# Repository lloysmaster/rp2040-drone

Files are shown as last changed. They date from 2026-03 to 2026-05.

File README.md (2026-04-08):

# 🛸 RP2040 Custom Flight Controller (PicoDrone)





Proyecto de **Controladora de Vuelo (FC)** desarrollada desde cero para el microcontrolador **RP2040**. Este firmware aprovecha las capacidades de hardware de la Raspberry Pi Pico (específicamente los bloques PIO) para gestionar protocolos de baja latencia.
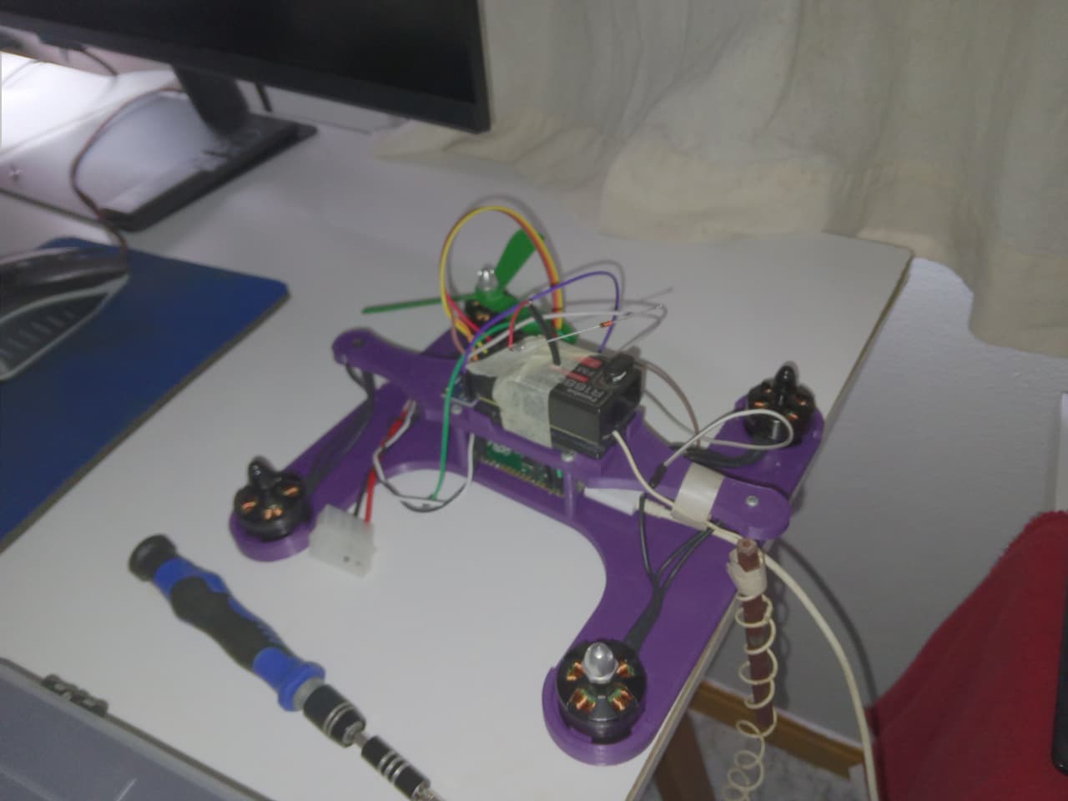
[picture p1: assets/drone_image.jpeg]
drone_image


[configurador personalizado](https://lloysmaster.github.io/)
/
 [repositorio](https://github.com/lloysmaster/lloysmaster.github.io)
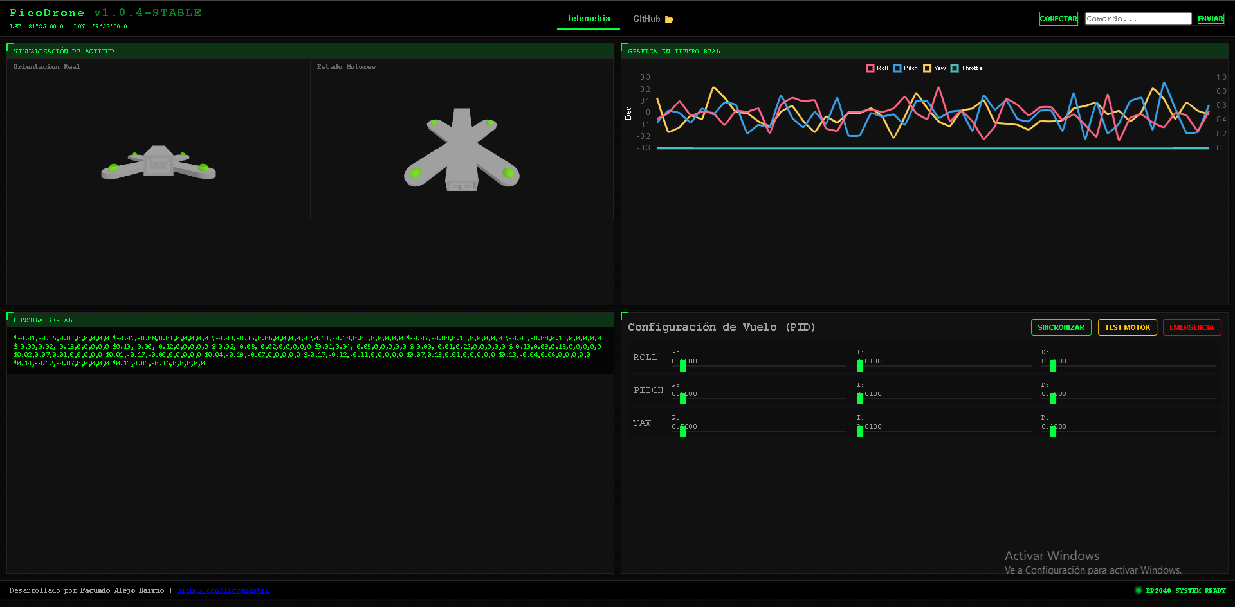
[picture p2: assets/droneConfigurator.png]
drone_image


---

## 🛠️ Especificaciones Técnicas

| Componente | Detalle | Protocolo/Conexión |
| :--- | :--- | :--- |
| **MCU** | Raspberry Pi Pico (RP2040) | Dual Core @ 125MHz |
| **IMU** | MPU6500 | **SPI** (Alta Velocidad) |
| **ESC** | BLHeli_S 20A | **DShot300** via PIO |
| **Radio RX** | Futaba 72MHz (Vintage) | **PPM** via PIO |
| **Motores** | Brushless 2204 | Configuración en "X" |

---

## 🚀 Estado del Desarrollo

Actualmente el sistema procesa la señal de radio y estabiliza los motores en un loop de **500Hz** para pruebas, actualmente 8khz.

- [x] **Lectura de Sensores:** Comunicación SPI con el MPU6500.
- [x] **Decodificador PPM:** Implementado en PIO para no cargar la CPU.
- [x] **Driver DShot:** Generación de tramas digitales para ESCs modernos.
- [y] **PID Control:** Estructura base funcional (en proceso de ajuste de constantes).
- [ ] **Seguridad:** Implementación de Failsafe y armado de motores.

### Diagrama de Motores (Configuración X)
```text
    M2 (FL) CW      M4 (FR) CCW
         \          /
          \  PICO  /
          /   FC   \
         /          \
    M1 (BL) CCW     M3 (BR) CW
```

---

## 🤝 Colaboración y Feedback

¡Hola! Este es un proyecto de aprendizaje y experimentación personal. No busco colaboradores activos, pero **estoy muy abierto a cualquier sugerencia, corrección o mejora** que quieras aportar al código.

Si tienes experiencia en estas áreas, tu feedback sería de gran ayuda:
* **Filtros:** Implementación de filtros (complementario o Kalman) para el ruido del giroscopio.
* **Control:** Sugerencias para el tuneo de las constantes PID.
* **PIO:** Optimizaciones en el uso de los State Machines del RP2040.
* **buenas practicas de codigo c/programacion de microcontroladores en c**

> [!IMPORTANT]
> **Seguridad:** Si decides clonar o probar este firmware, asegúrate de retirar las hélices de los motores por seguridad.

---

## 📂 Compilación y Uso

Este proyecto requiere el **Raspberry Pi Pico SDK** configurado en tu sistema.

1. Clona el repositorio.
2. Crea una carpeta llamada `build`.
3. Desde la terminal, dentro de `build`, ejecuta:
   ```bash
   cmake ..
   make
4. en la carpeta build encontraras un archivo .uf2 carga el archivo generado en tu Raspberry Pi Pico.

desde la interfaz de visual studio se hace todo mucho mas sencillo, directamente encotras botones como "compile" y "run" que cumplen de paso 2,3 y 4 respectivamente, si estas en linux quiza el 4 paso lo tengas que hacer manualmente

pequeño detalle, uso el sdk de pi pico desde la extencion de visual studio

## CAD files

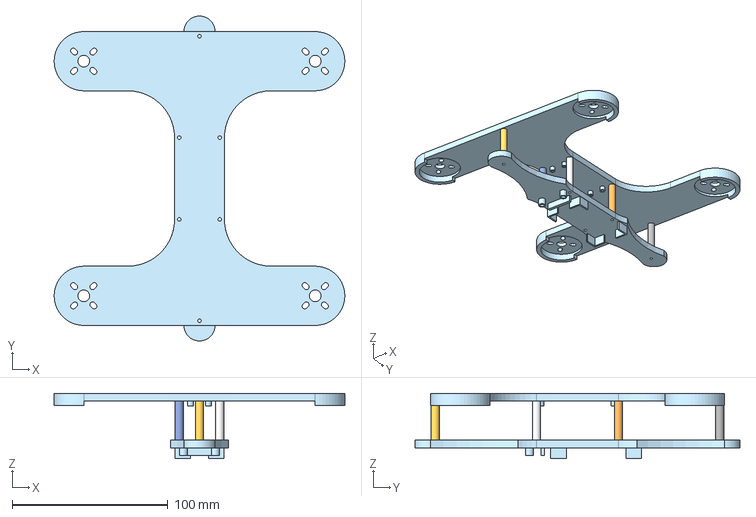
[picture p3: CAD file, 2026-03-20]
hardware/3d_models/droneFrame.step
186.5 x 208.5 x 42.0 mm

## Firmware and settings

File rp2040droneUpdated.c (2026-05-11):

#include <stdio.h>
#include <stdlib.h>
#include "pico/stdlib.h"
#include "hardware/spi.h"
#include "hardware/pio.h"
#include "hardware/clocks.h"
#include "pico/multicore.h"
#include "pico/mutex.h"

// includes de libs
#include "config.h"
#include "mpu6500.h"
#include "radio.h"
#include "pid.h"
#include "dshot.h"
#include "telemetry.h"
#include "console_handler.h"
#include "mixer.h"
#include "filter.h"
// Archivos PIO generados
#include "pio_ppm_rx.pio.h"
#include "pio_dshot.pio.h"

// --- ESTRUCTURAS DE DATOS ---
pid_axis_t pid_roll, pid_pitch, pid_yaw;
ppm_rx_t receptor;
dshot_config_t esc_motores;
uint16_t motor_test_val = 0;
telemetry_data_t t_data;
ema_filter_t filter_roll, filter_pitch, filter_yaw;

mutex_t my_mutex;

void core1_entry();

float gyro_x_offset = 0, gyro_y_offset = 0, gyro_z_offset = 0;
// --- PROTOTIPOS DE FUNCIONES ---
void init_hardware();
// --- INICIALIZACIÓN DE HARDWARE ---

void init_hardware()
{
    stdio_init_all();

    // Configuración SPI para MPU6500
    spi_init(MPU_SPI_INST, 20 * 1000 * 1000);
    gpio_set_function(PIN_SCK, GPIO_FUNC_SPI);
    gpio_set_function(PIN_MOSI, GPIO_FUNC_SPI);
    gpio_set_function(PIN_MISO, GPIO_FUNC_SPI);
    gpio_init(PIN_CS);
    gpio_set_dir(PIN_CS, GPIO_OUT);
    gpio_put(PIN_CS, 1);

    sleep_ms(100);
    mpu6500_write_reg(REG_PWR_MGMT_1, 0x01);
    mpu6500_write_reg(REG_GYRO_CONFIG, 0x18);

    radio_init(&receptor, pio0, 0, PPM_PIN);
    filter_init(&filter_roll, FILTER_ALPHA);
    filter_init(&filter_pitch, FILTER_ALPHA);
    filter_init(&filter_yaw, FILTER_ALPHA);

    // Inicializar con límites de anti-windup (ej: 100)
    pid_init(&pid_roll, ROLL_KP, ROLL_KI, ROLL_KD, PID_LIMIT_I);
    pid_init(&pid_pitch, PITCH_KP, PITCH_KI, PITCH_KD, PID_LIMIT_I);
    pid_init(&pid_yaw, YAW_KP, YAW_KI, YAW_KD, PID_LIMIT_I);

    // Configuración PIO DShot (pio1, 4 SMs)
    uint offset_ds = pio_add_program(pio1, &dshot300_program);
    dshot_init(&esc_motores, pio1, MOTOR_BASE_PIN);

    mpu6500_calibrate(&gyro_x_offset, &gyro_y_offset, &gyro_z_offset);
}
void core1_entry()
{
    uint32_t last_telemetry = 0;
    uint32_t last_radio     = 0;

    while (true) {
        uint32_t now = time_us_32();

        // Radio a 500 Hz (cada 2 ms) — tu receptor PPM va a 500 Hz
        if (now - last_radio >= 2000) {
            radio_update(&receptor);
            last_radio = now;
        }

        // Telemetría a ~25 Hz
        if (now - last_telemetry >= 40000) {
            telemetry_data_t snapshot;
            mutex_enter_blocking(&my_mutex);
            snapshot = t_data;
            mutex_exit(&my_mutex);
            telemetry_send(&snapshot);
            last_telemetry = time_us_32();
        }

        console_handle_input(&pid_roll, &pid_pitch, &pid_yaw, &motor_test_val);
    }
}
// --- BUCLE PRINCIPAL (MAIN) ---

int main()
{
    mutex_init(&my_mutex);
    init_hardware();
    multicore_launch_core1(core1_entry);
    int16_t gx, gy, gz;
    uint32_t next_loop_time = time_us_32();

    while (true)
    {
        // Control de tiempo del loop
        while (time_us_32() < next_loop_time)
            ;

        next_loop_time += TARGET_LOOP_US;

        // 1. Entradas (Consola y Radio)
        uint32_t chan_aileron = radio_get_channel(&receptor, 0);  // Roll
        uint32_t chan_elevator = radio_get_channel(&receptor, 1); // Pitch
        uint32_t chan_throttle = radio_get_channel(&receptor, 2); // Throttle
        uint32_t chan_rudder = radio_get_channel(&receptor, 3);   // Yaw

        static bool armed = false;
        bool arm_switch = (radio_get_channel(&receptor, 4) > 1500); // CH5


bool test_mode  = (motor_test_val > 0); // ← armado virtual por consola

if (!armed && !test_mode)
{
    if (arm_switch && chan_throttle < 1050)
    {
        armed = true;
        pid_reset(&pid_roll);
        pid_reset(&pid_pitch);
        pid_reset(&pid_yaw);
    }
    dshot_send_all(&esc_motores, 0, 0, 0, 0);
    continue;
}

// Desarmado en vuelo (solo si no estamos en test)
if (!arm_switch && !test_mode)
{
    armed = false;
    dshot_send_all(&esc_motores, 0, 0, 0, 0);
    continue;
}
        static uint32_t last_valid_ppm = 0;
uint32_t throttle_check = radio_get_channel(&receptor, 2);
if (throttle_check >= 900 && throttle_check <= 2100)
{
    last_valid_ppm = time_us_32();
} else if (!test_mode && time_us_32() - last_valid_ppm > 1500000) {
    armed = false;
    dshot_send_all(&esc_motores, 0, 0, 0, 0);
    continue;
}
        // 2. Sensores y Filtrado
        mpu6500_read_raw(&gx, &gy, &gz);
        float roll_raw = ((float)gx - gyro_x_offset) / GYRO_SCALE;
        float pitch_raw = ((float)gy - gyro_y_offset) / GYRO_SCALE;
        float yaw_raw = ((float)gz - gyro_z_offset) / GYRO_SCALE;

        // Aplicar filtros
        float roll_f = filter_apply(&filter_roll, roll_raw);
        float pitch_f = filter_apply(&filter_pitch, pitch_raw);
        float yaw_f = filter_apply(&filter_yaw, yaw_raw);

        // 3. Procesamiento PID
        float setpoint_roll = ((float)chan_aileron - 1500) / STICK_SENSITIVITY;
        float setpoint_pitch = ((float)chan_elevator - 1500) / STICK_SENSITIVITY;
        float setpoint_yaw = ((float)chan_rudder - 1500) / STICK_SENSITIVITY; // Asumiendo CH4 es Yaw

        float corr_roll = pid_update(&pid_roll, setpoint_roll, roll_f);
        float corr_pitch = pid_update(&pid_pitch, setpoint_pitch, pitch_f);
        float corr_yaw = pid_update(&pid_yaw, setpoint_yaw, yaw_f);
        if (motor_test_val > 10000)
        {
            // Si el valor es especial, enviamos comando de Beacon
            uint16_t beacon_cmd = motor_test_val - 10000;

            // IMPORTANTE: Para que el ESC acepte un comando, el bit de telemetría
            // suele ser necesario o el comando debe repetirse.
            dshot_send_all(&esc_motores, beacon_cmd, beacon_cmd, beacon_cmd, beacon_cmd);

            // Opcional: El beacon suele sonar mejor si se envía en ráfagas o
            // simplemente se deja de enviar aceleración.
        }
        else
        {
            // 1. Obtenemos el valor real del acelerador del radio (mapeado de 1000-2000 a 0-1000 aprox, o según tu mixer)
            int32_t throttle_val = (int32_t)chan_throttle - 1000;
            if (throttle_val < 50)
                throttle_val = 0;

            // Sumamos el valor de consola (test) y limitamos a 1000
            uint16_t total_throttle = (uint16_t)(throttle_val + motor_test_val);
            if (total_throttle > 1000)
                total_throttle = 1000;

            motor_output_t m_out = mixer_compute(total_throttle, corr_roll, corr_pitch, corr_yaw);
            dshot_send_all(&esc_motores, m_out.m1, m_out.m2, m_out.m3, m_out.m4);

            // 6. Telemetría actualizada
            static int count = 0;
if (count++ % 20 == 0) {
    mutex_enter_blocking(&my_mutex);
    t_data.roll       = roll_f;
    t_data.pitch      = pitch_f;
    t_data.yaw        = yaw_f;
    t_data.motors[0]  = m_out.m1;
    t_data.motors[1]  = m_out.m2;
    t_data.motors[2]  = m_out.m3;
    t_data.motors[3]  = m_out.m4;
    t_data.throttle   = total_throttle;
    mutex_exit(&my_mutex);
}
        }

    }
    // --- CORE 1: COMUNICACIONES Y TAREAS LENTAS ---
}

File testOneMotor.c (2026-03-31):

#include <stdio.h>
#include <stdlib.h>
#include "pico/stdlib.h"
#include "hardware/spi.h"
#include "hardware/pio.h"
#include "hardware/clocks.h"

// Archivos PIO generados
#include "pio_ppm_rx.pio.h"
#include "pio_dshot.pio.h"

// --- CONFIGURACIÓN DE PINES ---
#define PPM_PIN 2
#define MPU_SPI_INST spi1
#define PIN_MISO 12
#define PIN_CS 13
#define PIN_SCK 10
#define PIN_MOSI 11
#define MOTOR_BASE_PIN 16 // Motores en pines 16, 17, 18, 19

// --- CONFIGURACIÓN MPU6500 (REGISTROS) ---
#define REG_GYRO_CONFIG 0x1B
#define REG_PWR_MGMT_1 0x6B
#define REG_GYRO_XOUT_H 0x43
#define READ_BIT 0x80

// --- PARÁMETROS DE RECEPCIÓN PPM ---
#define NUM_CHANNELS 8
#define SYNC_THRESHOLD 2700

// --- ESTRUCTURAS DE DATOS ---
typedef struct
{
    float kp, ki, kd;
    float error_previo;
    float integral;
} pid_axis_t;

typedef struct
{
    PIO pio;
    uint sm;
} motor_t;

// --- VARIABLES GLOBALES ---
uint32_t raw_values[NUM_CHANNELS];
int current_channel = 0;
uint16_t motor_test_val = 0;

#define DSHOT_CMD_BEEP1 1
#define DSHOT_CMD_BEEP2 2
#define DSHOT_CMD_BEEP3 3
#define DSHOT_CMD_BEEP4 4
#define DSHOT_CMD_BEEP5 5

// Filtros y offsets
float roll_filtrado = 0;
float pitch_filtrado = 0;
float alpha = 0.2f; // Factor de filtro complementario/EMA
float gyro_x_offset = 0, gyro_y_offset = 0, gyro_z_offset = 0;

// Instancias de PID
pid_axis_t pid_roll = {.kp = 0.00f, .ki = 0.000f, .kd = 0.00f};
pid_axis_t pid_pitch = {.kp = 0.00f, .ki = 0.000f, .kd = 0.00f};
pid_axis_t pid_yaw = {.kp = 0.00f, .ki = 0.000f, .kd = 0.00f};

// Instancias de Motores
motor_t motores[4];

// --- PROTOTIPOS DE FUNCIONES ---
void init_hardware();
void process_ppm();
void check_console_input();
void calibrar_sensores();
float calcular_pid(pid_axis_t *pid, float setpoint, float lectura_actual);
void send_dshot_all(uint16_t m1, uint16_t m2, uint16_t m3, uint16_t m4);
uint16_t dshot_prepare_packet(uint16_t value);

// --- FUNCIONES MPU6500 (SPI) ---
static inline void cs_select() { gpio_put(PIN_CS, 0); }
static inline void cs_deselect() { gpio_put(PIN_CS, 1); }

void mpu_write(uint8_t reg, uint8_t data)
{
    uint8_t buf[] = {reg, data};
    cs_select();
    spi_write_blocking(MPU_SPI_INST, buf, 2);
    cs_deselect();
}

void mpu_read_gyro(int16_t *gx, int16_t *gy, int16_t *gz)
{
    uint8_t reg = REG_GYRO_XOUT_H | READ_BIT;
    uint8_t buffer[6];
    cs_select();
    spi_write_blocking(MPU_SPI_INST, &reg, 1);
    spi_read_blocking(MPU_SPI_INST, 0, buffer, 6);
    cs_deselect();
    *gx = (buffer[0] << 8) | buffer[1];
    *gy = (buffer[2] << 8) | buffer[3];
    *gz = (buffer[4] << 8) | buffer[5];
}

// --- LÓGICA DE CONTROL Y VUELO ---

void calibrar_sensores()
{
    int32_t gx_sum = 0, gy_sum = 0, gz_sum = 0;
    const int muestras = 500;
    printf("Calibrando... NO MUEVAS EL DRON\n");

    for (int i = 0; i < muestras; i++)
    {
        int16_t gx, gy, gz;
        mpu_read_gyro(&gx, &gy, &gz);
        gx_sum += gx;
        gy_sum += gy;
        gz_sum += gz;
        sleep_us(1000);
    }
    gyro_x_offset = (float)gx_sum / muestras;
    gyro_y_offset = (float)gy_sum / muestras;
    gyro_z_offset = (float)gz_sum / muestras;
    printf("Calibracion lista. Offsets: X:%.2f Y:%.2f\n", gyro_x_offset, gyro_y_offset);
}

float calcular_pid(pid_axis_t *pid, float setpoint, float lectura_actual)
{
    float error = setpoint - lectura_actual;

    // Término Integral con anti-windup
    pid->integral += pid->ki * error;
    if (pid->integral > 100)
        pid->integral = 100;
    else if (pid->integral < -100)
        pid->integral = -100;

    // Término Derivativo
    float d_term = pid->kd * (error - pid->error_previo);
    pid->error_previo = error;

    return (pid->kp * error) + pid->integral + d_term;
}

// --- LÓGICA DSHOT ---

uint16_t dshot_prepare_packet(uint16_t value)
{
    if (value == 0)
        return 0;
    uint16_t packet = (value << 1);
    uint16_t checksum = 0;
    uint16_t temp_packet = packet;

    for (int i = 0; i < 3; i++)
    {
        checksum ^= (temp_packet & 0x0F);
        temp_packet >>= 4;
    }
    return (packet << 4) | (checksum & 0x0F);
}

void send_dshot_all(uint16_t m1, uint16_t m2, uint16_t m3, uint16_t m4)
{
    uint16_t vals[4] = {m1, m2, m3, m4};
    for (int i = 0; i < 4; i++)
    {
        uint16_t packet = dshot_prepare_packet(vals[i]);
        pio_sm_put_blocking(motores[i].pio, motores[i].sm, packet << 16);
    }
}

// --- COMUNICACIÓN Y ENTRADA ---

void check_console_input()
{
    int c = getchar_timeout_us(0);
    if (c != PICO_ERROR_TIMEOUT)
    {
        static char buffer[32];
        static int idx = 0;

        if (c == '\n' || c == '\r')
        {
            buffer[idx] = '\0';
            if (idx > 0)
            {
                char type = buffer[0];
                float val = atof(&buffer[1]);

                if (type == 'M' || type == 'm')
                {
                    motor_test_val = (uint16_t)val;
                    printf(">> Motor Test Set: %d\n", motor_test_val);
                }
                else if (type == 'P' || type == 'p')
                {
                    pid_roll.kp = pid_pitch.kp = val;
                    printf(">> Kp (P) actualizado a: %.4f\n", val);
                }
                else if (type == 'I' || type == 'i')
                {
                    pid_roll.ki = pid_pitch.ki = val;
                    pid_roll.integral = pid_pitch.integral = 0;
                    printf(">> Ki (I) actualizado a: %.4f (Integral reseteada)\n", val);
                }
                else if (type == 'D' || type == 'd')
                {
                    pid_roll.kd = pid_pitch.kd = val;
                    printf(">> Kd (D) actualizado a: %.4f\n", val);
                }
                else if (type == 'S' || type == 's')
                {
                    printf("\n--- PID STATUS ---\nP: %.4f | I: %.4f | D: %.4f\n------------------\n",
                           pid_roll.kp, pid_roll.ki, pid_roll.kd);
                }
            }
            idx = 0;
        }
        else if (idx < 31)
        {
            buffer[idx++] = (char)c;
        }
    }
}

void process_ppm()
{
    while (!pio_sm_is_rx_fifo_empty(pio0, 0))
    {
        uint32_t val = pio_sm_get(pio0, 0);
        if (val > SYNC_THRESHOLD)
        {
            current_channel = 0;
        }
        else if (current_channel < NUM_CHANNELS)
        {
            if (val > 400 && val < 2400)
                raw_values[current_channel] = val;
            current_channel++;
        }
    }
}

// --- INICIALIZACIÓN DE HARDWARE ---
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

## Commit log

2026-02-26 agregado test de motores temporal, en caso de usarlo cambiar el contenido de rp2040droneUpdated.c por el de testOneMotor.c y compilar
2026-02-26 nuevo diagrama de conneccion
    [circuito drone.dsn]
2026-03-20 actualizacion, modelos 3d y circuito, ahora procesable por ia este ultimo
    [circuito drone.dsn, droneFrame.step]
2026-03-31 agregado de imagen
2026-03-31 correccion de mixer
2026-05-11 subida de ultimo cambios localas
